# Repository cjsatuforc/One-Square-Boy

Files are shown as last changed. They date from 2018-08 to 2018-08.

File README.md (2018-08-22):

# One-Square-Boy
A one square inch control board for Teacup compatible 3D printers.

This project was created for the Return of the Square Inch Project on Hackaday.io.

Specs:
- ATmega328 microcontroller
- Four STSPIN220 low-voltage stepper motor drivers
- MJD122T4 MOSFET to control extruder temperature
- Power connectors for always-on fans 
- Connector for endstop signals
- Four layer board

To Do:
1. Receive board from OSHPark.
2. Populate.
3. Modify Teacup firmware to work with current setup, change pin definitions.
4. Gut Replikator Mini V1 and hook the new system up with 3D printed case and heatsinks.
5. Create video of print and complete submission for the competition.

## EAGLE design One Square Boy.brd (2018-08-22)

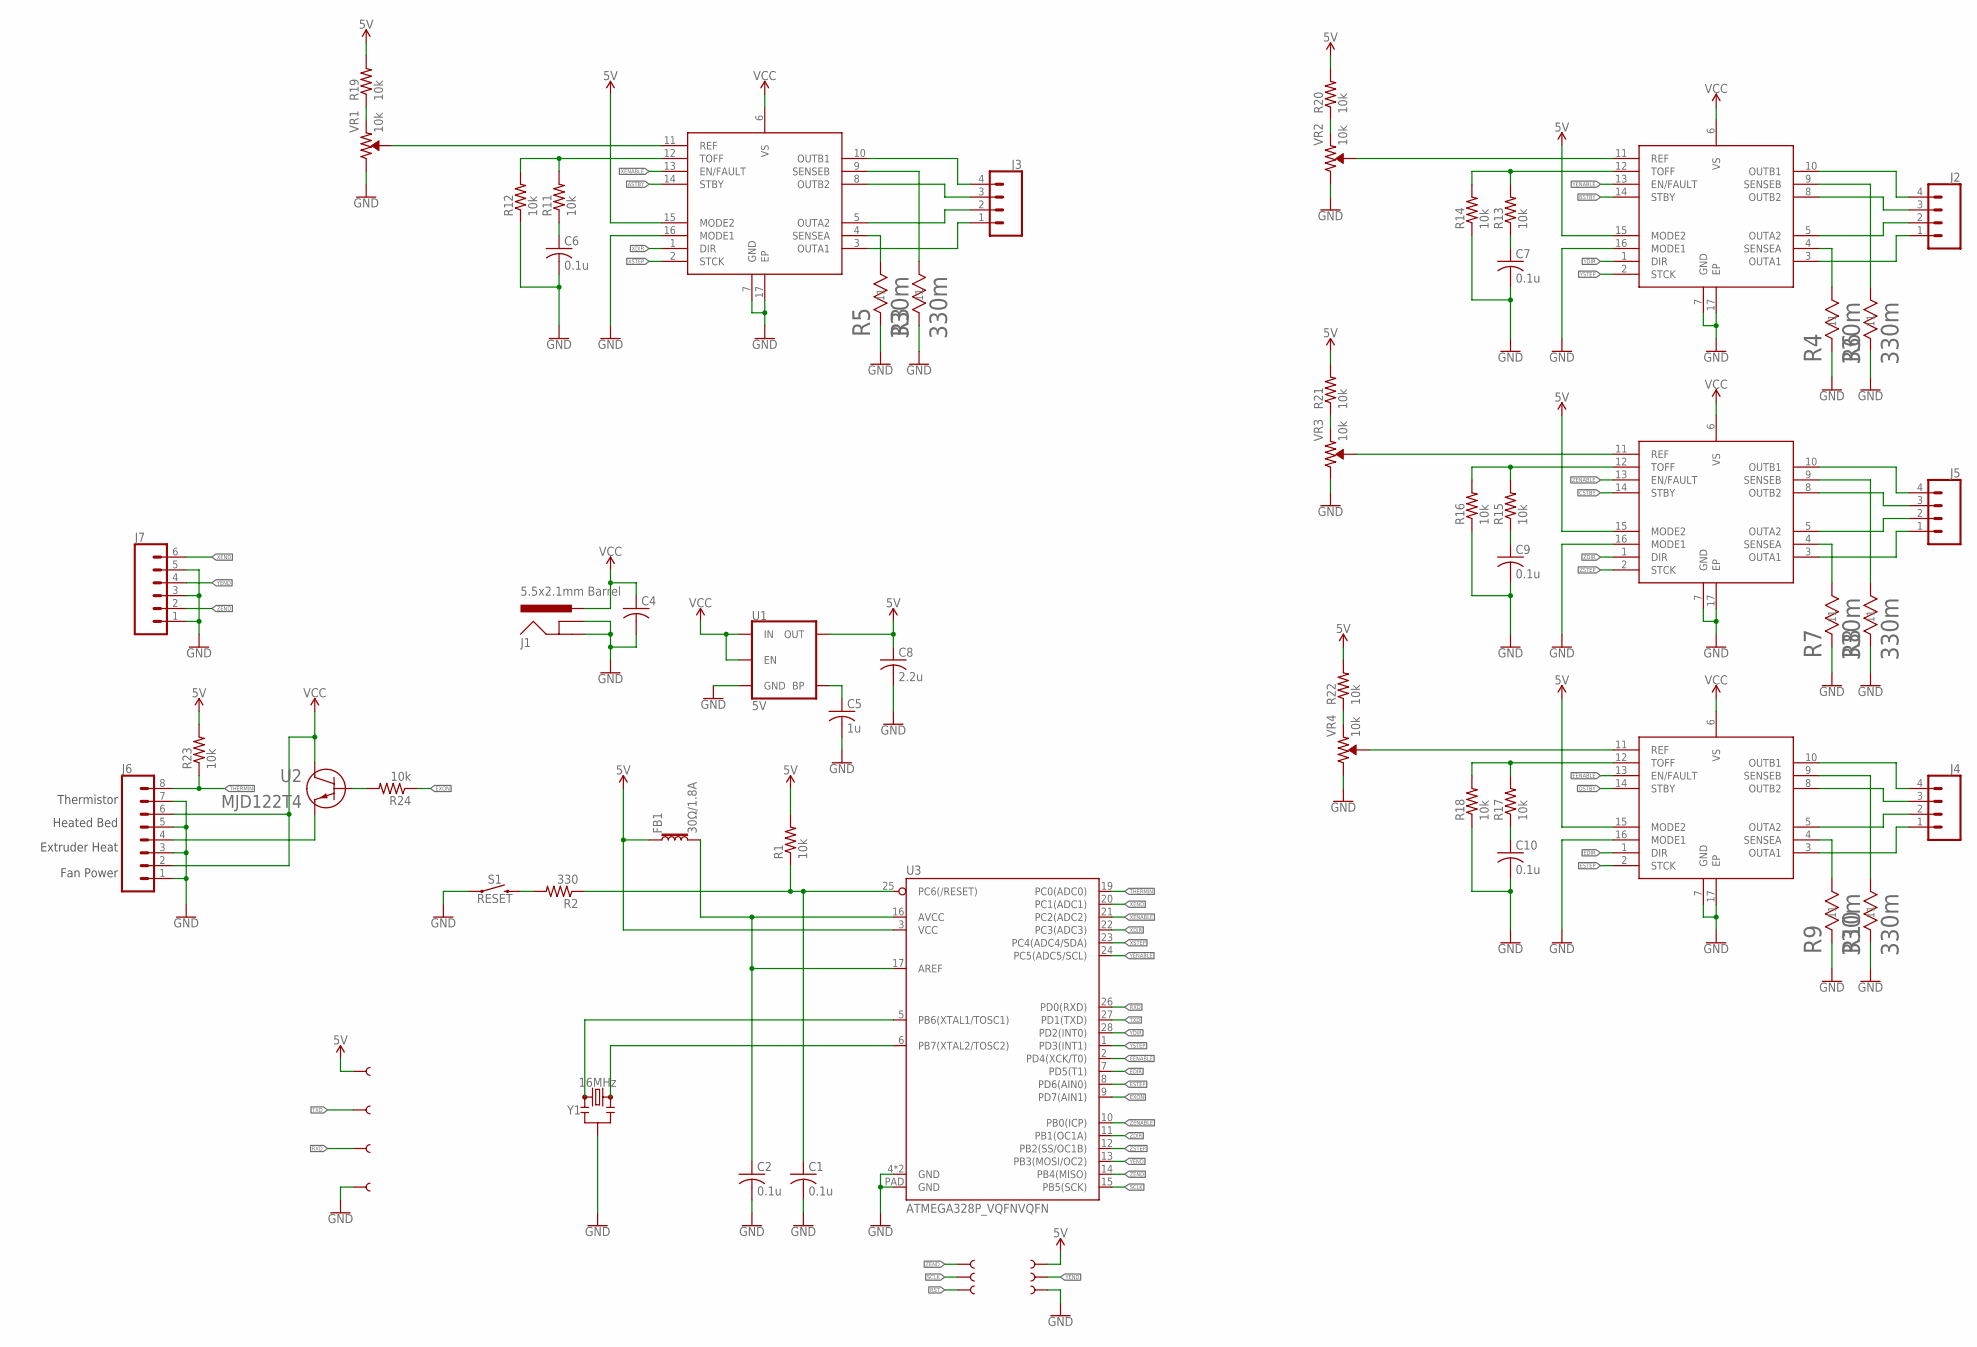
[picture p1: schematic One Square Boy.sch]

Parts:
C1, C2, C6, C7, C9, C10: 0.1u; C0402
C4: C-USC1206; C1206
C5: 1u; C0402
C8: 2.2u; C0402
FB1: 30Ω/1.8A; 0603
J1: 5.5x2.1mm Barrel; POWER_JACK_SMD
J2, J3, J4, J5: CONN_04SMD2; 1X04_1MM_RA
J6: CONN_08BM08B-SRSS-TB; BM08B-SRSS-TB
J7: CONN_06SMD-1MM; 1X06-1MM
R1, R11, R12, R13, R14, R15, R16, R17, R18, R19, R20, R21, R22, R23, R24: 10k; R0402
R2: 330; R0402
R3, R4, R5, R6, R7, R8, R9, R10: 330m; RES_2012-L
S1: RESET; TACTILE_SWITCH_SMD_4.6X2.8MM
TP1, TP2, TP3, TP4, TP5, TP6, TP7, TP8, TP9, TP10: TEST-POINT3X5; PAD.03X.05
U1: 5V; SOT23-5
U2: MJD122T4; DPAK
U3: ATMEGA328P_VQFNVQFN; VQFN-28
U$1, U$2, U$3, U$4: STSPIN220; QFN50P300X300X100-17N
VR1, VR2, VR3, VR4: 10k; TRIMPOT-SMD-TC33X
Y1: 16MHz; RESONATOR-SMD-3.2X1.3

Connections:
5V: C8.1, FB1.1, R1.2, R19.2, R20.2, R21.2, R22.2, R23.2, TP4.P$1, TP10.P$1, U1.5 (OUT), U3.3 (VCC), U$1.15 (MODE2), U$2.15 (MODE2), U$3.15 (MODE2), U$4.15 (MODE2)
ASTBY: U$1.14 (STBY)
AVCC: C2.1, FB1.2, U3.16 (AVCC), U3.17 (AREF)
BSTBY: U$2.14 (STBY)
CSTBY: U$3.14 (STBY)
DSTBY: U$4.14 (STBY)
EDIR: U3.7 (PD5(T1)), U$4.1 (DIR)
EENABLE: U3.2 (PD4(XCK/T0)), U$4.13 (EN/FAULT)
ESTEP: U3.8 (PD6(AIN0)), U$4.2 (STCK)
EXON: R24.1, U3.9 (PD7(AIN1))
GND: C1.2, C2.2, C4.2, C5.2, C6.2, C7.2, C8.2, C9.2, C10.2, J1.GND (GNDBREAK), J1.P$4 (GND), J6.1, J6.3, J6.5, J6.7, J7.1, J7.3, J7.5, R3.1 (11), R4.1 (11), R5.1 (11), R6.1 (11), R7.1 (11), R8.1 (11), R9.1 (11), R10.1 (11), R12.1, R14.1, R16.1, R18.1, S1.1, S1.2 (1), TP6.P$1, TP7.P$1, U1.2 (GND), U3.4 (GND), U3.18 (GND), U3.PAD (GND), U$1.7 (GND), U$1.16 (MODE1), U$1.17 (EP), U$2.7 (GND), U$2.16 (MODE1), U$2.17 (EP), U$3.7 (GND), U$3.16 (MODE1), U$3.17 (EP), U$4.7 (GND), U$4.16 (MODE1), U$4.17 (EP), VR1.1 (CW), VR2.1 (CW), VR3.1 (CW), VR4.1 (CW), Y1.2
unnamed: R2.2, S1.3 (2), S1.4 (2)
unnamed: U3.5 (PB6(XTAL1/TOSC1)), Y1.1
unnamed: U3.6 (PB7(XTAL2/TOSC2)), Y1.3
unnamed: J4.4, U$4.10 (OUTB1)
unnamed: J4.3, U$4.8 (OUTB2)
unnamed: J4.2, U$4.5 (OUTA2)
unnamed: J4.1, U$4.3 (OUTA1)
unnamed: J5.2, U$3.5 (OUTA2)
unnamed: J5.1, U$3.3 (OUTA1)
unnamed: J5.4, U$3.10 (OUTB1)
unnamed: J5.3, U$3.8 (OUTB2)
unnamed: J2.4, U$2.10 (OUTB1)
unnamed: J2.3, U$2.8 (OUTB2)
unnamed: J2.2, U$2.5 (OUTA2)
unnamed: J2.1, U$2.3 (OUTA1)
unnamed: J3.4, U$1.10 (OUTB1)
unnamed: J3.3, U$1.8 (OUTB2)
unnamed: J3.1, U$1.3 (OUTA1)
unnamed: J3.2, U$1.5 (OUTA2)
unnamed: R9.2 (22), U$4.4 (SENSEA)
unnamed: R10.2 (22), U$4.9 (SENSEB)
unnamed: R7.2 (22), U$3.4 (SENSEA)
unnamed: R8.2 (22), U$3.9 (SENSEB)
unnamed: R4.2 (22), U$2.4 (SENSEA)
unnamed: R6.2 (22), U$2.9 (SENSEB)
unnamed: R5.2 (22), U$1.4 (SENSEA)
unnamed: R3.2 (22), U$1.9 (SENSEB)
unnamed: C5.1, U1.4 (BP)
unnamed: R11.2, R12.2, U$1.12 (TOFF)
unnamed: C6.1, R11.1
unnamed: R13.2, R14.2, U$2.12 (TOFF)
unnamed: C7.1, R13.1
unnamed: R24.2, U2.1 (B1)
unnamed: R15.2, R16.2, U$3.12 (TOFF)
unnamed: C9.1, R15.1
unnamed: J6.4, U2.2 (E2)
unnamed: R17.2, R18.2, U$4.12 (TOFF)
unnamed: C10.1, R17.1
unnamed: R20.1, VR2.3 (CCW)
unnamed: U$4.11 (REF), VR4.2 (WIPER)
unnamed: U$3.11 (REF), VR3.2 (WIPER)
unnamed: U$2.11 (REF), VR2.2 (WIPER)
unnamed: U$1.11 (REF), VR1.2 (WIPER)
unnamed: R19.1, VR1.3 (CCW)
unnamed: R21.1, VR3.3 (CCW)
unnamed: R22.1, VR4.3 (CCW)
RST: C1.1, R1.1, R2.1, TP3.P$1, U3.25 (PC6(/RESET))
RXD: TP8.P$1, U3.26 (PD0(RXD))
SCLK: TP2.P$1, U3.15 (PB5(SCK))
THERMIN: J6.8, R23.1, U3.19 (PC0(ADC0))
TXD: TP9.P$1, U3.27 (PD1(TXD))
VCC: C4.1, J1.VIN0 (PWR), J6.2, J6.6, U1.1 (IN), U1.3 (EN), U2.3 (C3), U$1.6 (VS), U$2.6 (VS), U$3.6 (VS), U$4.6 (VS)
XDIR: U3.22 (PC3(ADC3)), U$1.1 (DIR)
XENABLE: U3.21 (PC2(ADC2)), U$1.13 (EN/FAULT)
XEND: J7.6, U3.20 (PC1(ADC1))
XSTEP: U3.23 (PC4(ADC4/SDA)), U$1.2 (STCK)
YDIR: U3.28 (PD2(INT0)), U$2.1 (DIR)
YENABLE: U3.24 (PC5(ADC5/SCL)), U$2.13 (EN/FAULT)
YEND: J7.4, TP5.P$1, U3.13 (PB3(MOSI/OC2))
YSTEP: U3.1 (PD3(INT1)), U$2.2 (STCK)
ZDIR: U3.11 (PB1(OC1A)), U$3.1 (DIR)
ZENABLE: U3.10 (PB0(ICP)), U$3.13 (EN/FAULT)
ZEND: J7.2, TP1.P$1, U3.14 (PB4(MISO))
ZSTEP: U3.12 (PB2(SS/OC1B)), U$3.2 (STCK)

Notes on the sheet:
Thermistor
Heated Bed
Extruder Heat
Fan Power

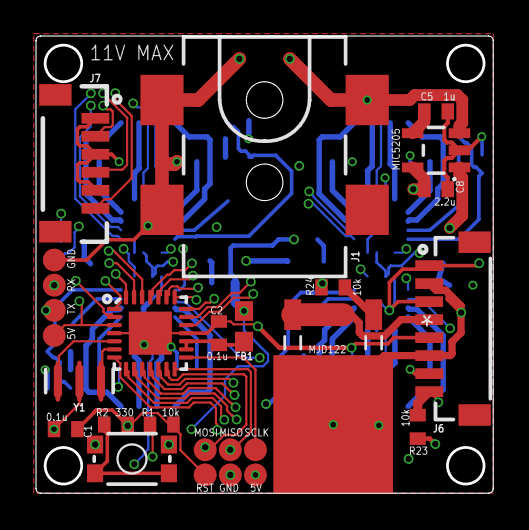
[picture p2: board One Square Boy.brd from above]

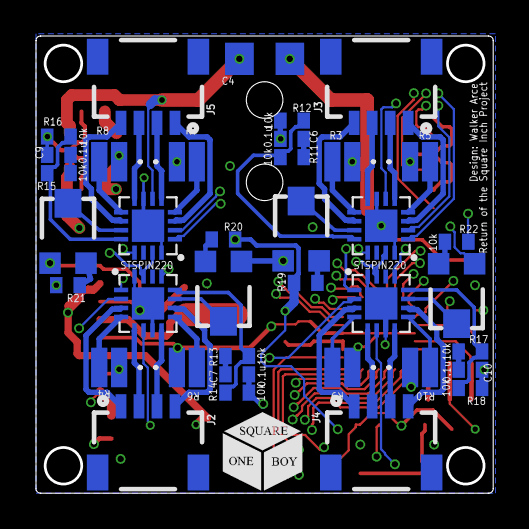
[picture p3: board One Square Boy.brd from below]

Board: 4 copper layers, 25.4 x 25.4 mm, 64 parts (37 on the bottom side), 71 nets.

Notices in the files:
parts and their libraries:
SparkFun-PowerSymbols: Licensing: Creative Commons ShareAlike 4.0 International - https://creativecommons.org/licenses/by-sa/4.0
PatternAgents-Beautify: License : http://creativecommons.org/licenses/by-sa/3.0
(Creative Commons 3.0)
